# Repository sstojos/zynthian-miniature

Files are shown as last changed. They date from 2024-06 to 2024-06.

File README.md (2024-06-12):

# zynthian-miniature
# Overview
This is repository that store schematics and PCB design for basic PCB with MIDIs, Sound Card and 4 encoders for [zynthian](https://www.zynthian.org). It can also be used for any other raspberry pi audio software. 

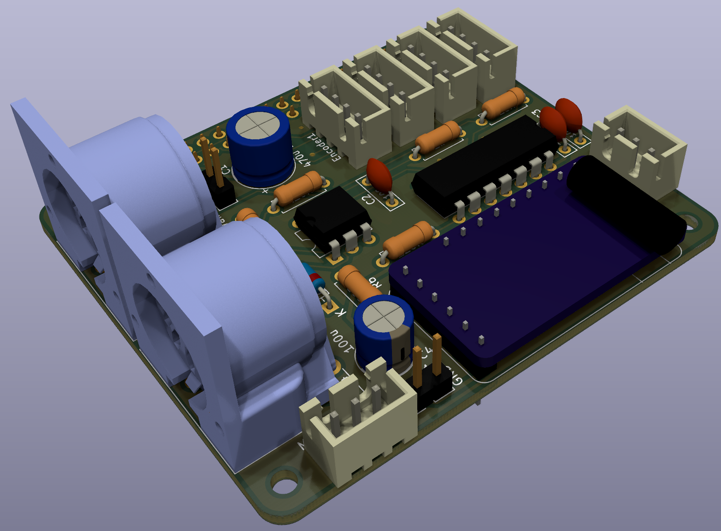
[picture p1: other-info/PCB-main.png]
PCB Main

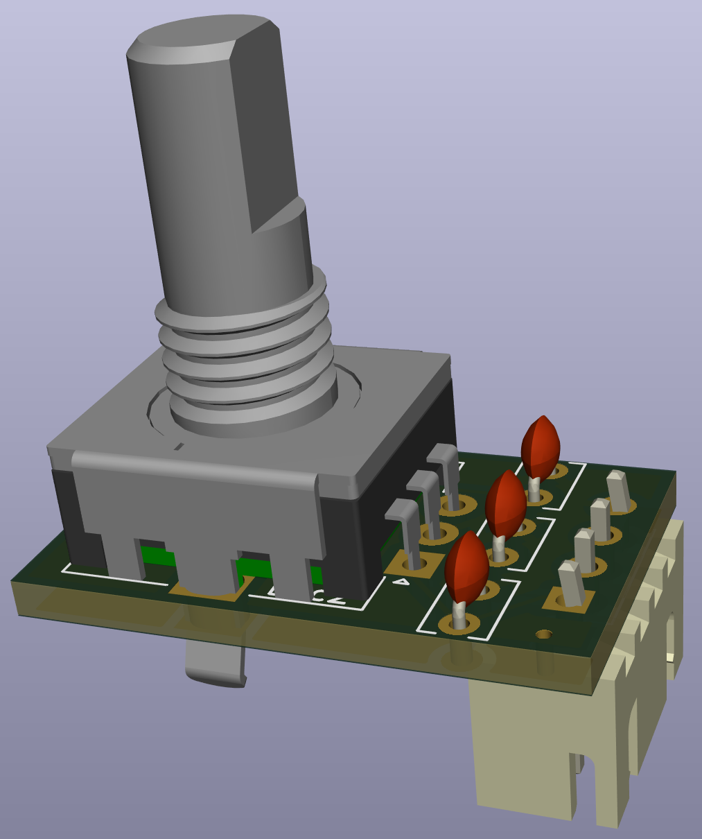
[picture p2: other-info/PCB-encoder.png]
Encoder


This is designed in KiCad 6.0. It is inspired by clumsy MIDI project.

It comes as a single PCB that need to be split into 5: one main PCB and 4 encoder PCBs.
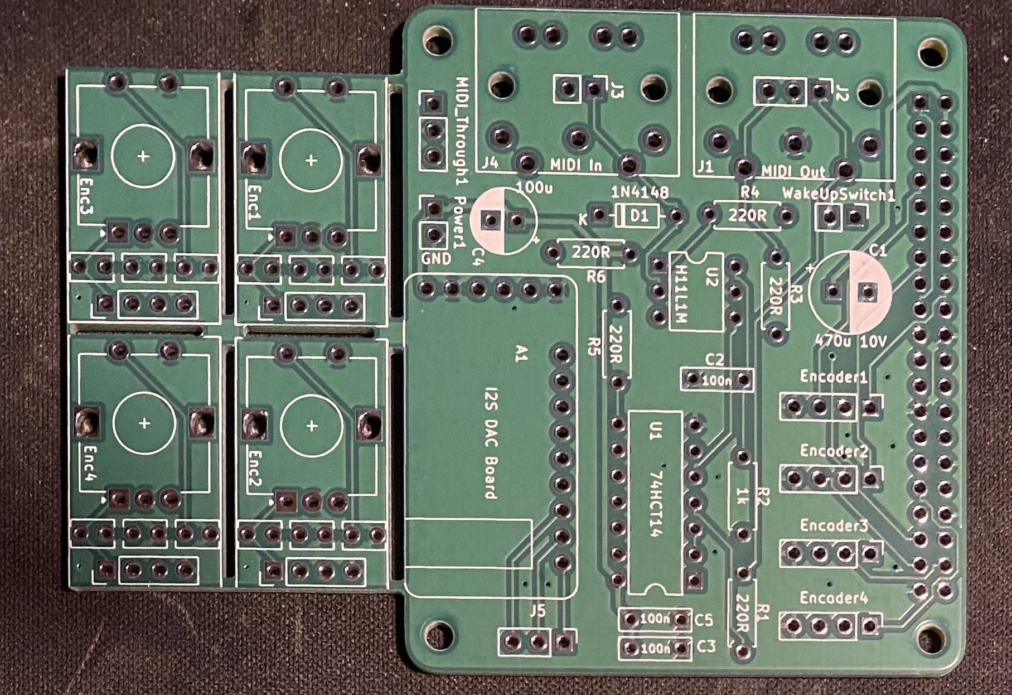
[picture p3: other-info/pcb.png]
5 PCBs


Here is the KiCad schematics screenshot:
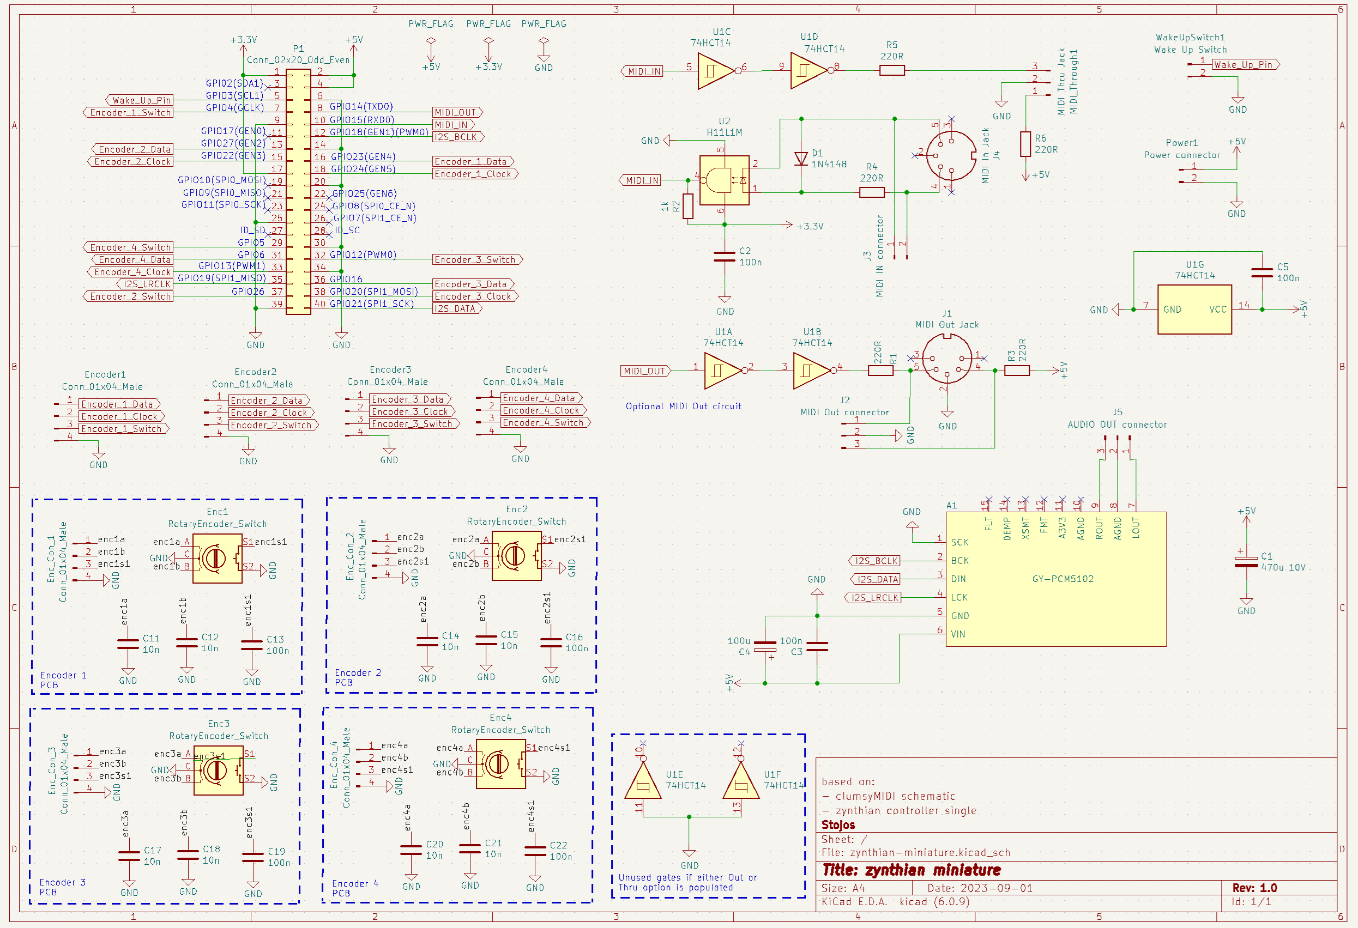
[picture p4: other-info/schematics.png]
schematics


# BOM
Interactive BOM can be found [here](https://raw.githack.com/sstojos/zynthian-miniature/main/bom/ibom.html).

# Usage scenarious

## JST connectors can be replaced with pinheader connectors
Connectors for encoder wiring are JST 2.5mm connectors but standard 2.54mm pin header connectors can also be used instead.

## PCB mounted MIDI connectors can be replaced with panel mounted MIDI connectors
It can be also used  with MIDI and AUDIO panel connectors. Here is how would you wire external panel connectors.
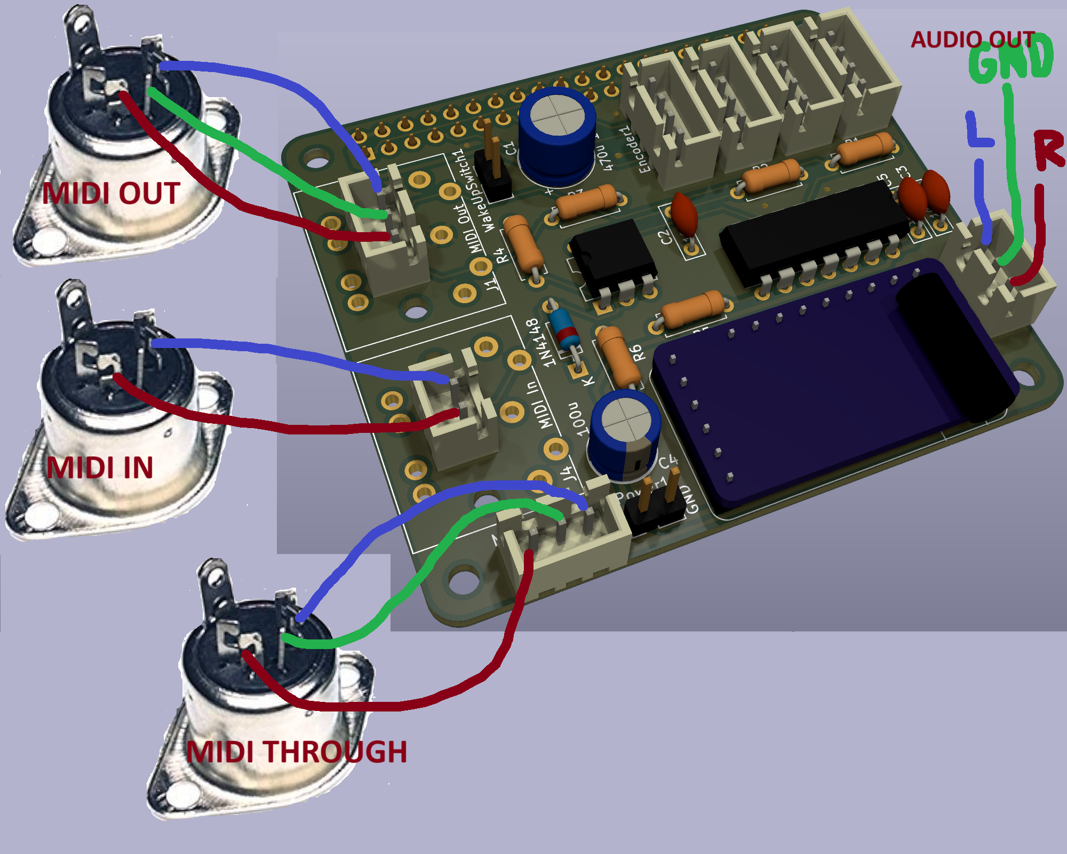
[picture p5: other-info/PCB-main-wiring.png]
external wirring


NOTE: Due to limited size of raspberry pi HUT, JST connectors for MIDI panel connectors are in the same place on PCB where two (IN and OUT) MIDI PCB mountable connectors are. Therefore you can only install JST connectors or MIDI PCB connectors but not both on the same PCB. MIDI through connector is only available through JST connector.

## It can be used with another sound card 
Sound card must not be installed if another sound card is connected to raspberry pi. I2S sound cards can not share the same rpi pins.
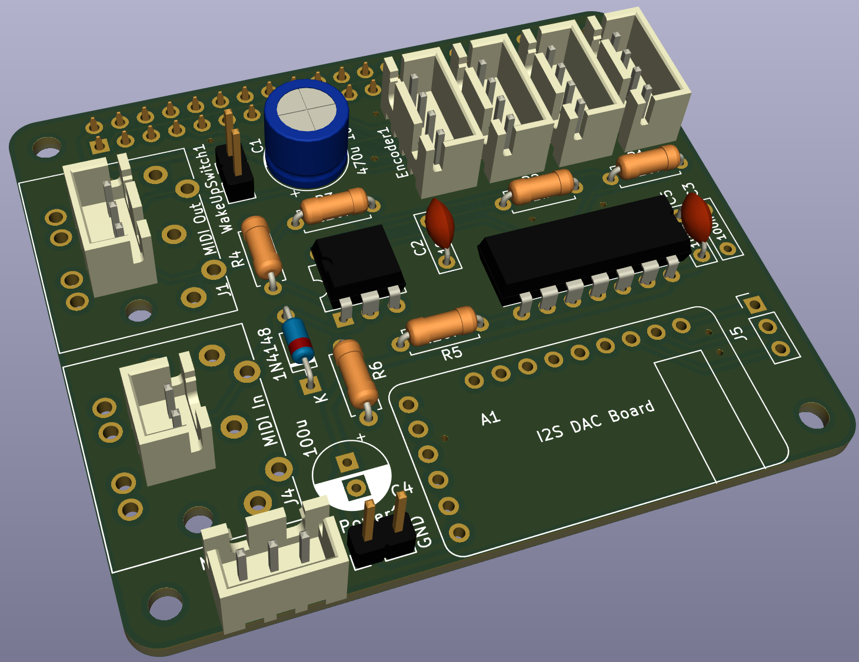
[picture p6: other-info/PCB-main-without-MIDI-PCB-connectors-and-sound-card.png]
without sound card


NOTE: can not be used with another audio card that have AUDIO IN (ADC) such as Hifyberry DAC+ ADC or DAC2 PRO ADC because encoder 3 B pin is wired to RPI pin 38 which is often  used by audio cards with ADC for audio in data. In this case there is a need to brake line from encoder 3 B connector to rpi 38 pin on PCB and  patch (solder wire) from encoder 3 b pin to another available rpi pin. Finnaly, wiring configuration in zynthian webconfig need to be changed accordingly. It is an easy patch. 

# Zynthian Webconfig

## Sound Card
Audio: HifiBerry DAC+ light

## Wiring
* Wiring Layout: Dummies
* Advance Configuration: Enabled
* Encoders A-pins: 5,3,28,23
* Encoders B-pins: 4,2,27,22
* Switches pins: 7,25,26,21

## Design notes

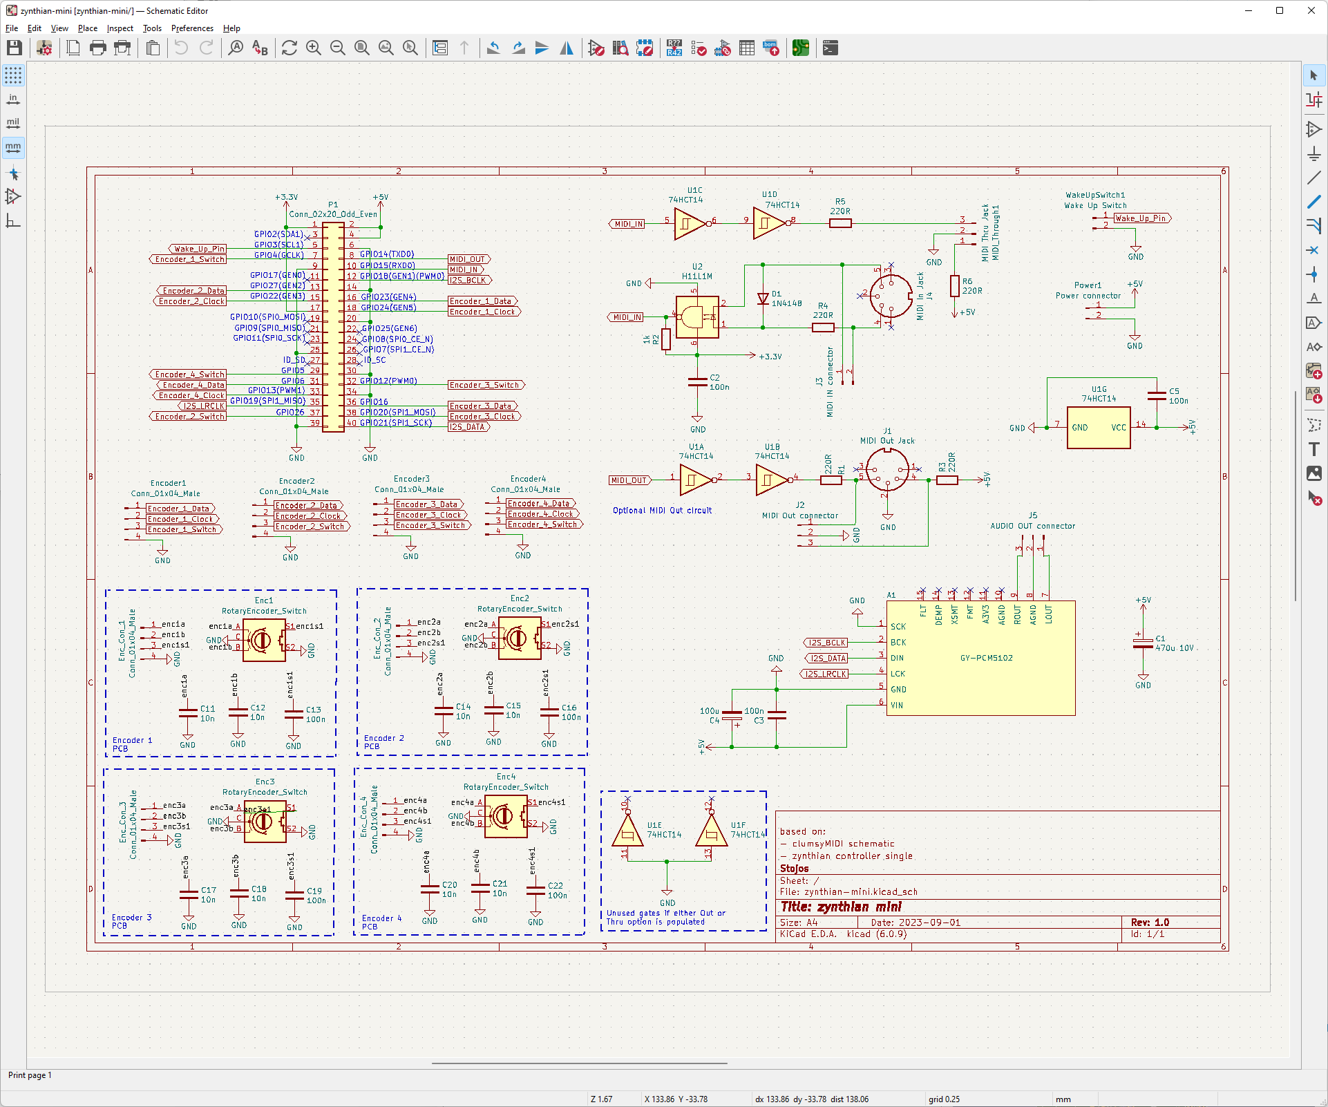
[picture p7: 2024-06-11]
other-info/openscad/zynthian-mini-schematics.png

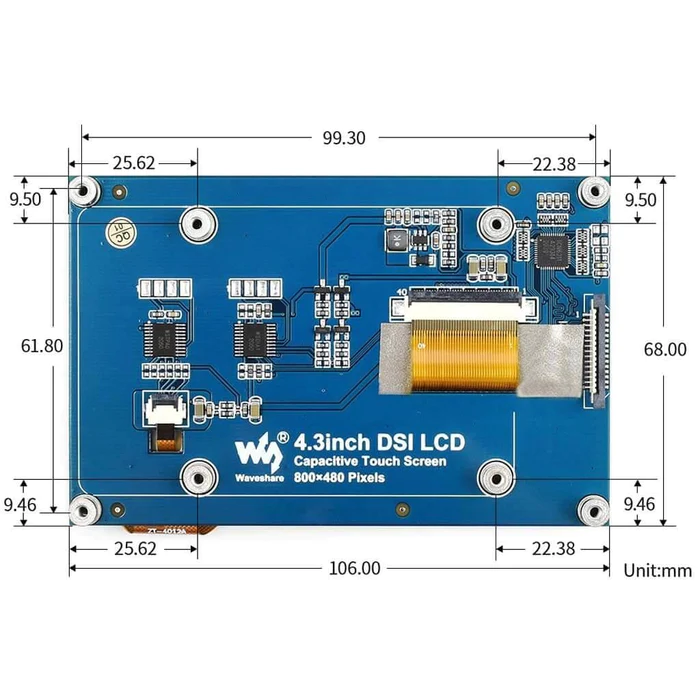
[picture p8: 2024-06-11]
other-info/openscad/waveshare-4.3-dimensions.png

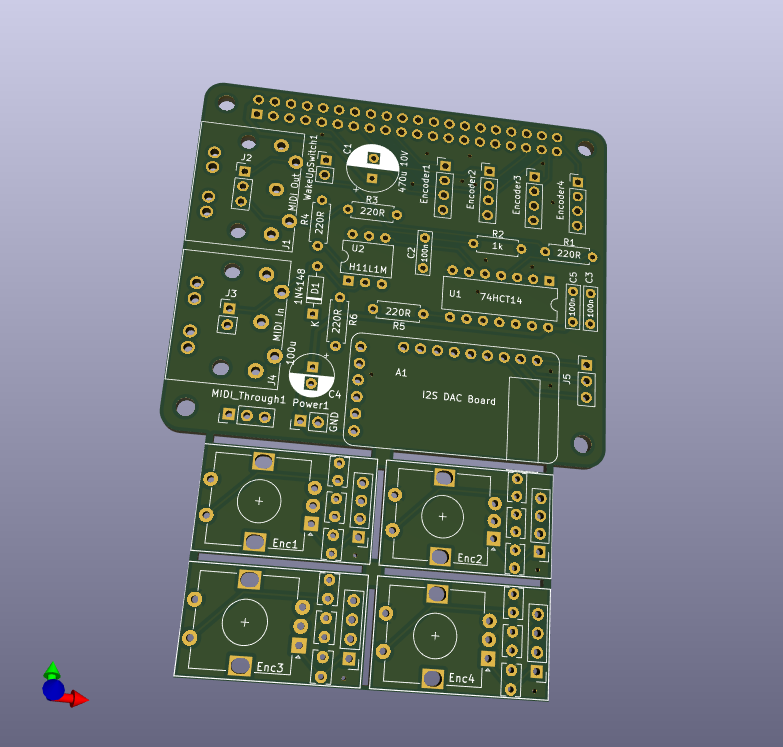
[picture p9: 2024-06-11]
other-info/openscad/zynthian-min-pcbi.png

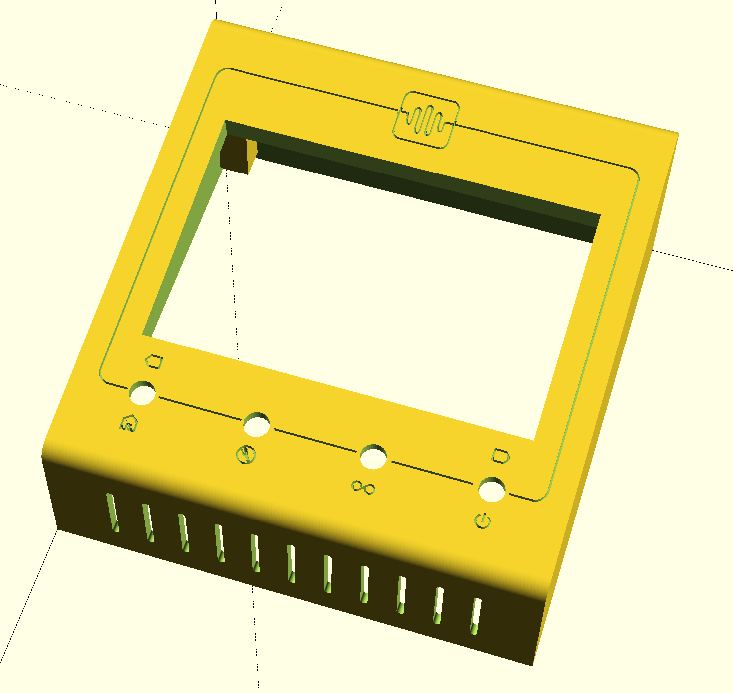
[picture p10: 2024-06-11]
other-info/openscad/zynthina-mini-case-top.png

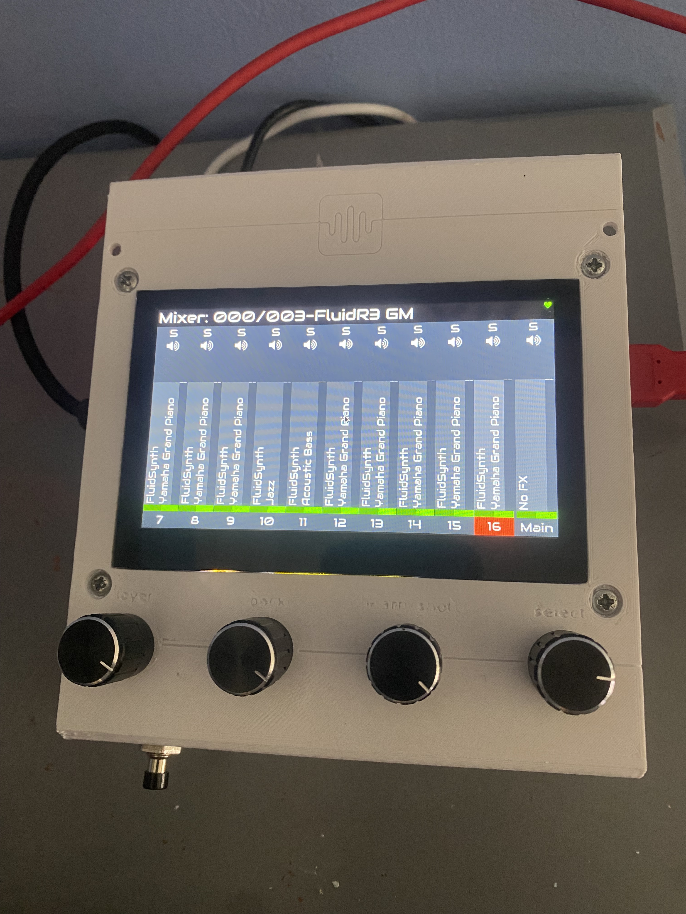
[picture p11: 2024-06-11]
other-info/openscad/zynthian-top.jpg

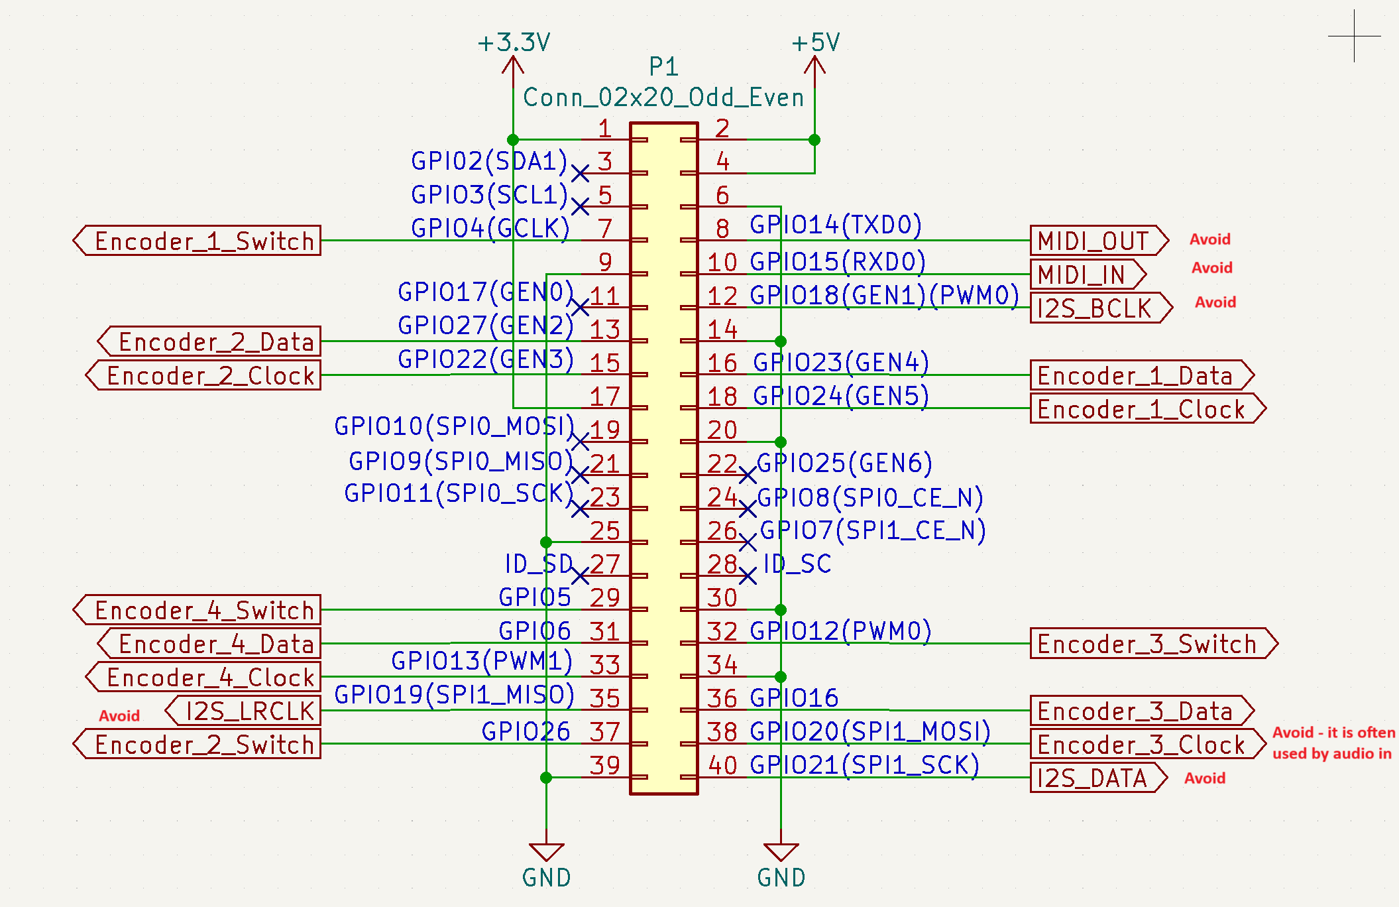
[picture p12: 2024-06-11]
other-info/connector.png

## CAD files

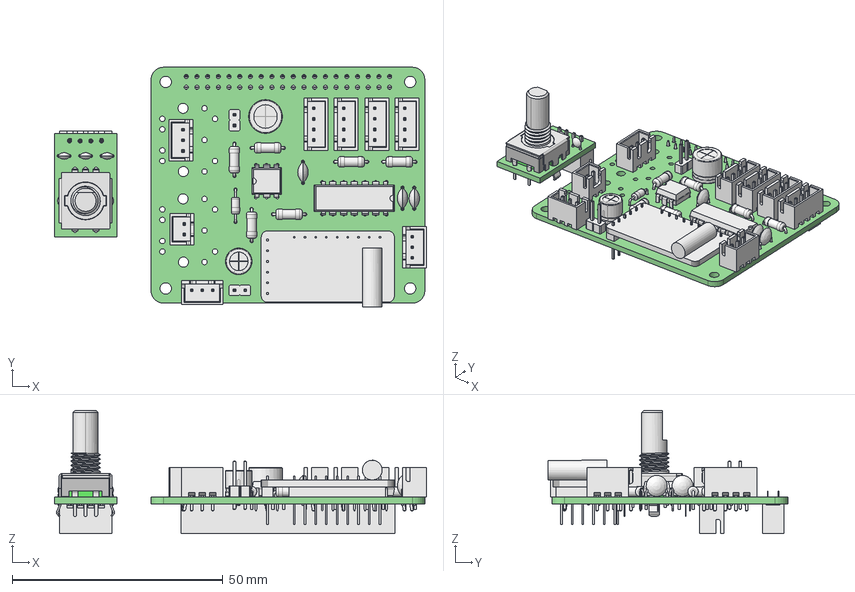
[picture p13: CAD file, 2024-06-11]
other-info/main-board-and-encoder.FCStd
88.3 x 56.9 x 29.2 mm
zynthian-miniature - main-only PCB
_autosave-zynthian-miniature - encoder PCB

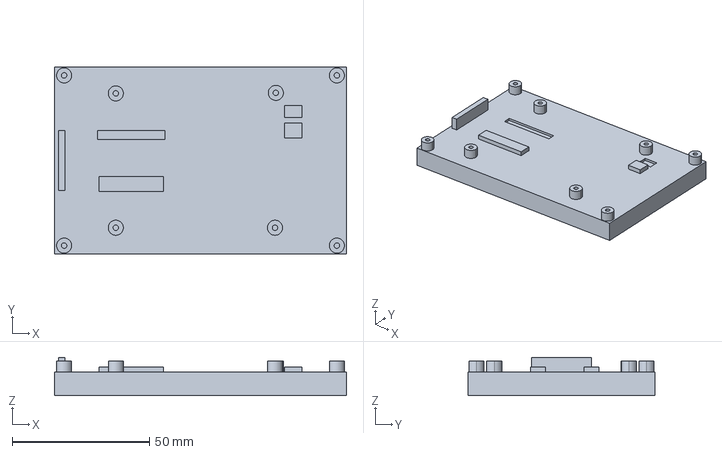
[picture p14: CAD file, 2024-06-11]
other-info/openscad/0329.stp
106.2 x 68.0 x 14.0 mm

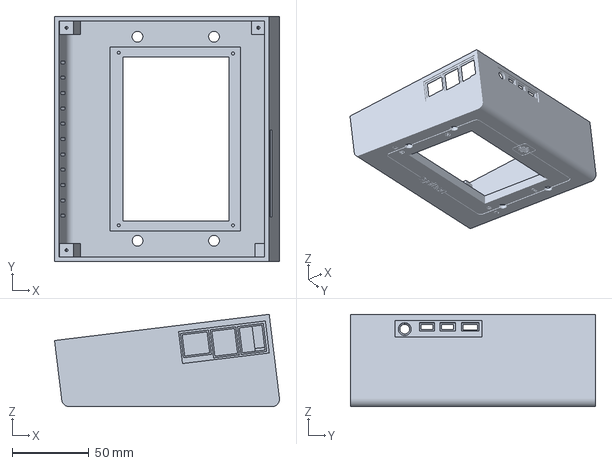
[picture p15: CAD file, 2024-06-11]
other-info/openscad/orcaslicer/top.3mf
146.7 x 160.0 x 60.2 mm

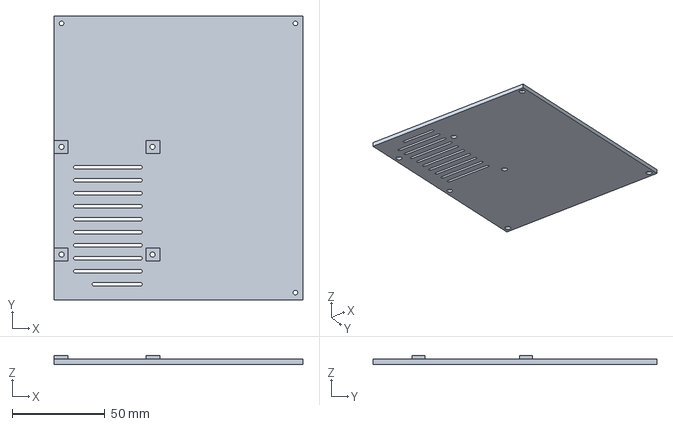
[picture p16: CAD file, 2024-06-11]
other-info/openscad/STLs/bottom.3mf
134.0 x 153.0 x 5.00 mm

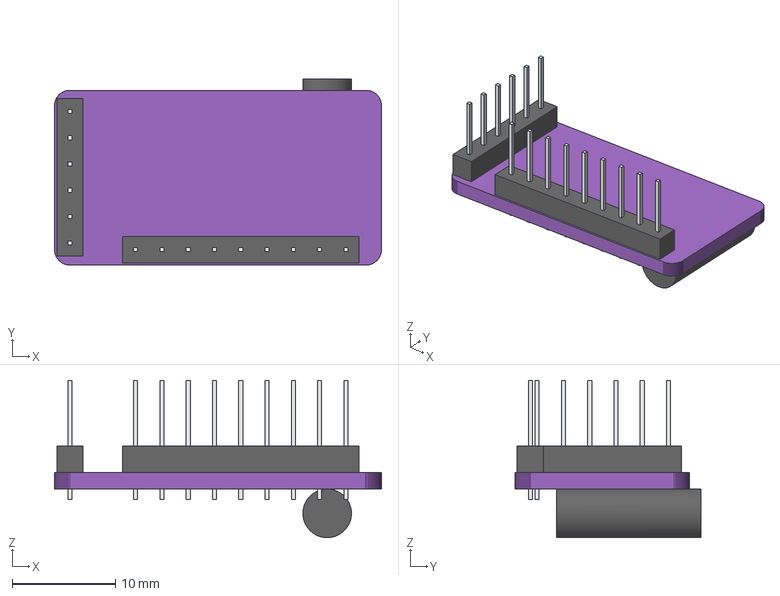
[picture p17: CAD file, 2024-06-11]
PCM5102-I2S.step
31.6 x 18.0 x 15.2 mm

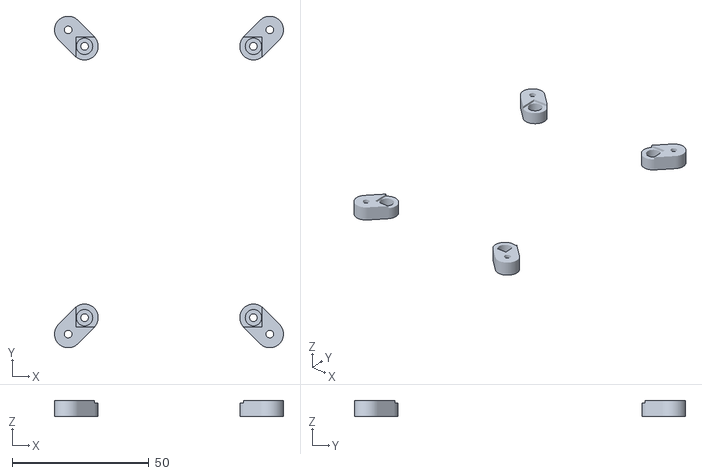
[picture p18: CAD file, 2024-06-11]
other-info/openscad/STLs/screen_mountings.stl
83.8 x 121.3 x 6.00

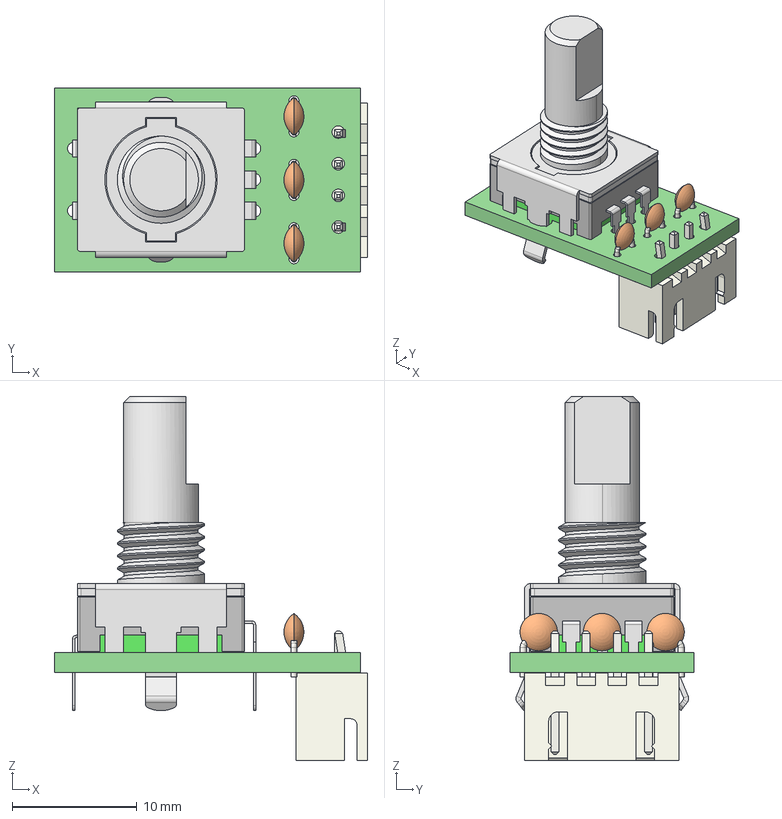
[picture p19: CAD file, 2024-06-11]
zynthian-miniature - encoder.step
25.1 x 14.8 x 29.2 mm
_autosave-zynthian-miniature - encoder PCB

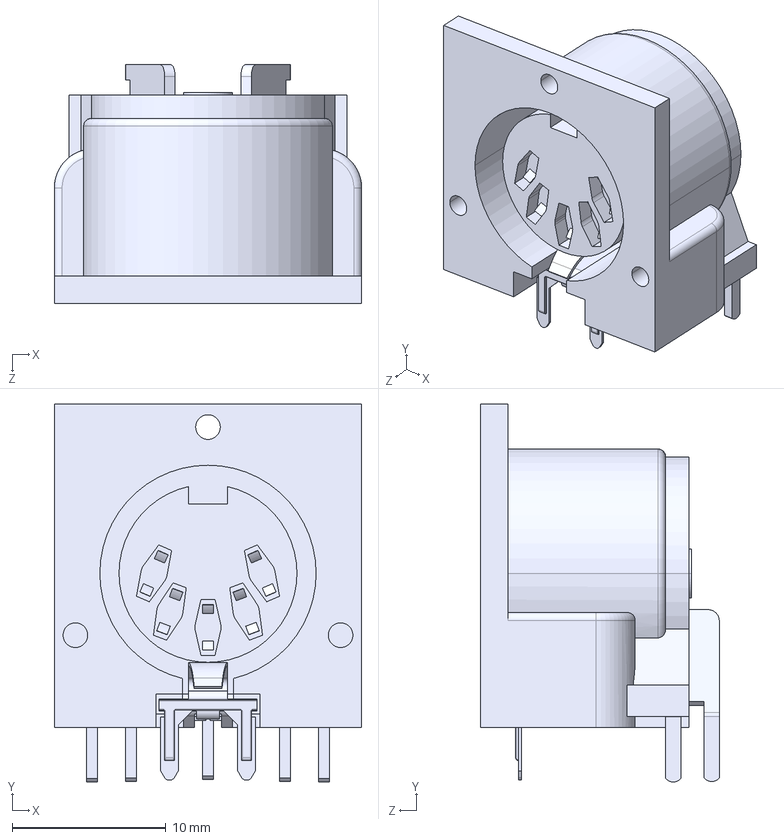
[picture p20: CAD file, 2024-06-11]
midi-connector.step
20.0 x 24.5 x 15.5 mm

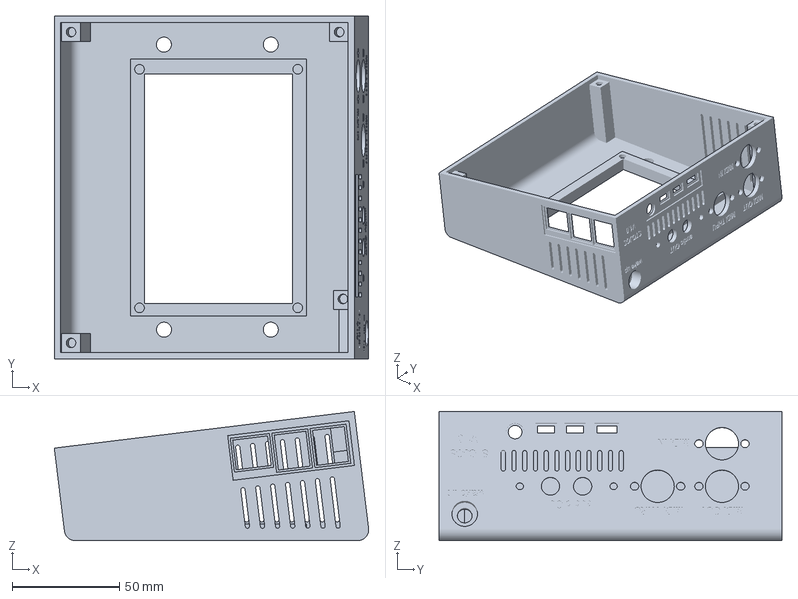
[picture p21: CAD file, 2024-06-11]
other-info/openscad/STLs/top.3mf
146.7 x 160.0 x 60.2 mm

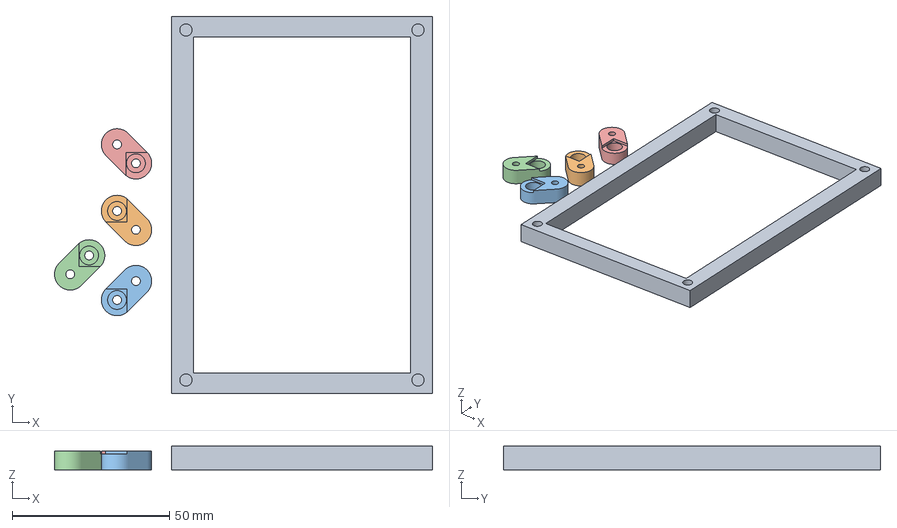
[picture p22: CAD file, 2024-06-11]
other-info/openscad/STLs/mount_test.3mf
120.2 x 120.0 x 7.60 mm
mount_test.stl
screen_mountings.stl_4
screen_mountings.stl_3
screen_mountings.stl_1
screen_mountings.stl_2

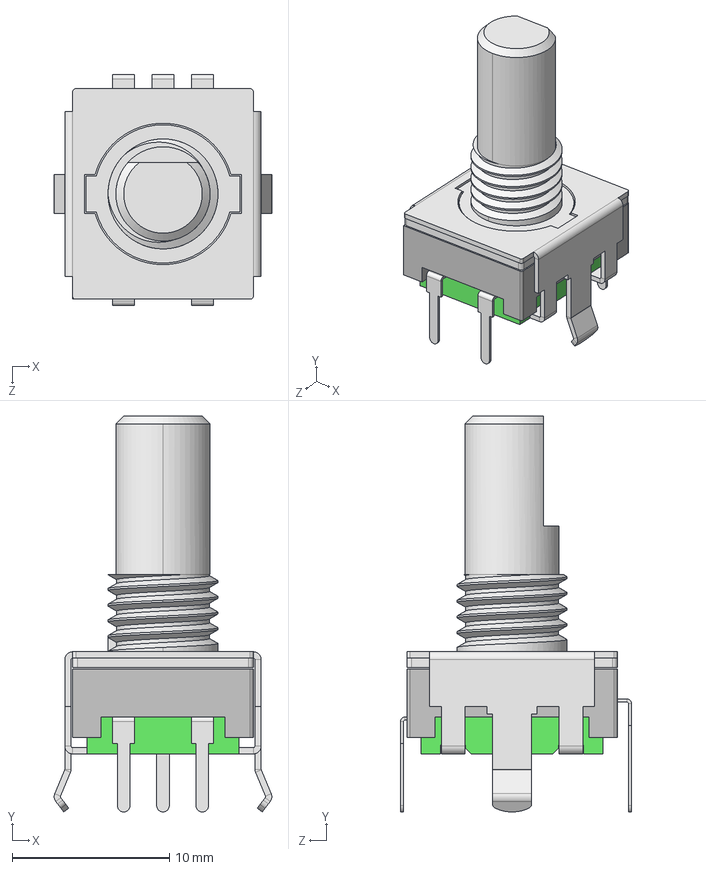
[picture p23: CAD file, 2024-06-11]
rotary-encoder.step
13.9 x 25.2 x 14.7 mm

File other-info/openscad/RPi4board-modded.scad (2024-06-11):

//------------------------------------------------------------------------
// OpenSCAD models of miscellaneous components and devices:
// various Raspberry Pi models, SainSmart Relays, PCD8544 LCD, etc.
//
// Author:      Niccolo Rigacci <niccolo@rigacci.org>
// Version:     1.0 2017-12-14
// License:     GNU General Public License v3.0
// Modified:    by Richard Jelbert 5th January 2021 for RPi 4
//------------------------------------------------------------------------

// Interference for 3D union(), difference() and intersection();
// used to avoid the manifold problem.
interf = 0.2;

//------------------------------------------------------------------------
// Matrix of 2.54 mm pins.
//------------------------------------------------------------------------
module pin_headers(cols, rows) {
    w = 2.54; h = 2.54; p = 0.65;
    for(x = [0 : (cols -1)]) {
        for(y = [0 : (rows  - 1)]) {
            translate([w * x, w * y, 0]) {
                union() {
                    color("black") cube([w, w, h]);
                    //color("gold")  translate([(w - p) / 2, (w - p) / 2, -3]) cube([p, p, 11.54]);
                }
            }
        }
    }
}

//------------------------------------------------------------------------
// Sub-models for the Raspberry Pi 4 Model
//------------------------------------------------------------------------

module ethernet_connector(x, y, z, cut=false) {
    if(!cut) {
        color("silver") cube([x, y, z]);
    }
    if(cut) {
        translate([-0.5,5,-0.5]) color("silver") cube([x+1, y, z+1]);
    }
}
module usb_connector(x, y, z, cut=false) {
    f = 0.6; // Flange
    if(!cut) {
        color("silver") cube([x, y, z]);
        translate([-f, y - f, -f])
            color("silver") cube([x + f * 2, f, z + f * 2]);
    }
    if(cut) {
        //color("silver") cube([x, y, z]);
        translate([-f-0.5, 5, -f-0.5])
            color("silver") cube([x + f * 2+1, y+10, z + f * 2+1]);
    }
}
module hdmi_connector(x, y, z, cut=false) {
    if(!cut) {
        color("silver") cube([x, y, z]);
    }
    if(cut) {
        translate([3,-0.5,-0.5]) color("silver") cube([x+5, y+1, z+1]);
    }
}
module usbc_connector(x, y, z, cut=false) {
    color("silver") cube([x, y, z]);
}
module capacitor(d, h) {
    color("silver") cylinder(r=(d / 2), h=h);
}
module micro_sd_card() {
    color("silver")   translate([1.5,  0.0, -1.5]) cube([12, 12.5, 1.5]);
    color("orange") translate([2, -3.2, -1.0]) cube([11, 15, 1.0]);
}
module audio_video(size_x, cut=false) {
    fn = 64;
    if(!cut) {
        color([58/255, 58/255, 58/255]) {
            cube([size_x, 7, 5.6]);
            translate([size_x, 7 / 2, 5.6 / 2]) rotate([0,90,0]) cylinder(d=5.6, h=2.6, $fn = fn);
        }
    }
    if(cut) {
        color([58/255, 58/255, 58/255]) {
            cube([size_x, 7, 5.6]);
            translate([size_x, 7 / 2, 5.6 / 2]) rotate([0,90,0]) cylinder(d=5.6+0.5, h=10, $fn = fn);
        }
    }
}
module cpu() {
    color("silver")
    cube([15,15,2.4]);
}

module ram() {
    color("black")
    cube([15,10.2,1]);
}

module wifi(){
    color("silver")
    cube([12,10,1.5]); 
}   

module cameracon(){
    color("black")
    cube([22,2.5,5.5]);
}


//------------------------------------------------------------------------
// Raspberry Pi 4 Model B
//------------------------------------------------------------------------
//board_raspberrypi_4_model_b(cut=true);
//board_raspberrypi_4_model_b(cut=false);
module board_raspberrypi_4_model_b(cut=false) {
    fn = 64;
    x  = 56;     y = 85;    z = 1.40;  // Measured PCB size
    ex = 15.9; ey = 21.5; ez = 13.5;   // Ethernet port size
    ux = 13.1; uy = 17.1; uz = 15.5;   // Measured USB connector size
    hx = 7.80; hy = 6.5; hz = 3;  // Measured micro HDMI connector size
    mx =  7.60; my =  9; mz = 3.20;  // Measured USB-C power connector size
    // The origin is the lower face of PCB.
    if(!cut) {
        translate([0, 0, z]) {
            
            translate([56-32.5-7.5,3.5+25.75-7.5,0])  cpu();
            translate([56-32.5-7.5,3.5+43.75-7.5,0])  ram();
            translate([7,6.5,0])    wifi();
            translate([(56/2)-12,(4-1.25),0]) cameracon();
            translate([(56)-22.3,(45),0]) cameracon();
            translate([1.0, 7.1, 0])    pin_headers(2, 20);
            translate([x-(ex/2)-45.75, y - ey + 2.1, 0])    ethernet_connector(ex, ey, ez);
            translate([x-(ux/2)-27, 85 - uy + 2.1, 0])  usb_connector(ux, uy, uz);
            translate([x-(ux/2)-9, 85 - uy + 2.1, 0])   usb_connector(ux, uy, uz);
            translate([x - hx + 1.8, (3.5+7.7+14.8-(hy/2)), 0]) hdmi_connector(hx, hy, hz);
            translate([x - hx + 1.8, (3.5+7.7+14.8+13.5-(hy/2)), 0])    hdmi_connector(hx, hy, hz);
            translate([x - 12.8, 50, 0])    audio_video(12.8);
            translate([x - mx + 1, (3.5+7.7-(my/2)), 0])    usbc_connector(mx, my, mz);
            //translate([20.5, 0.8, -z])  micro_sd_card();
            translate([0, 0, -z]) {
                color("green") linear_extrude(height=z)
                    difference() {
                        hull() {
                            translate([  3,   3]) circle(r=3, $fn = fn);
                            translate([x-3,   3]) circle(r=3, $fn = fn);
                            translate([x-3, y-3]) circle(r=3, $fn = fn);
                            translate([  3, y-3]) circle(r=3, $fn = fn);
                        }
                        raspberrypi_4_model_b_holes();
                    }
            }
        }
    }
    
    if(cut) {
       translate([0, 0, z]) {
            translate([x-(ex/2)-45.75, y - ey + 2.1, 0])    ethernet_connector(ex, ey, ez, cut=true);
            translate([x-(ux/2)-27, 85 - uy + 2.1, 0])  usb_connector(ux, uy, uz, cut=true);
            translate([x-(ux/2)-9, 85 - uy + 2.1, 0])   usb_connector(ux, uy, uz, cut=true);
            translate([x - hx + 1.8, (3.5+7.7+14.8-(hy/2)), 0]) hdmi_connector(hx, hy, hz, cut=true);
            translate([x - hx + 1.8, (3.5+7.7+14.8+13.5-(hy/2)), 0])    hdmi_connector(hx, hy, hz, cut=true);
            translate([x - 12.8, 50, 0])    audio_video(12.8, cut=true);
            //translate([x - mx + 1, (3.5+7.7-(my/2)), 0])    usbc_connector(mx, my, mz, cut=true);
       }
   }
}

//------------------------------------------------------------------------
// Holes for Raspberry Pi 4 Model B
//------------------------------------------------------------------------
module raspberrypi_4_model_b_holes() {
    x = 56;
    fn = 64;
    translate([3.5, 3.5])            circle(r=(2.75 / 2), $fn=fn);
    translate([(x - 3.5), 3.5])      circle(r=(2.75 / 2), $fn=fn);
    translate([3.5, 3.5 + 58])       circle(r=(2.75 / 2), $fn=fn);
    translate([(x - 3.5), 3.5 + 58]) circle(r=(2.75 / 2), $fn=fn);
}



//board_raspberrypi_4_model_b();

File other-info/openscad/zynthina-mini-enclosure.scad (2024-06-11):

$fn=124;


//render_all_disassembled();
color("SaddleBrown") render_all_assembled();

module render_all_assembled() {    
    

}

module render_all_disassembled() {    
    
}

//mounting();
module mounting() {

    difference() {
        union() {
            hull() {
                cylinder(r=5,h=10);
            translate([-7,-7,0])cylinder(r=5,h=10);
            }
            hull() {
                translate([-1.5,-1.5,0])cylinder(r=5,h=3);
                translate([-7,-7,0])cylinder(r=5,h=3);
            }
        }
        translate([0,0,3])cylinder(r=3,h=4.5);
        translate([0,0,5])cylinder(r=1.4,h=8);
        translate([-3.25,-3.25,-1]) cube([10,10,5.5]);
        translate([-7,-7,-1])cylinder(r=1,h=5);
        translate([-7,-7,10-4])cylinder(r=1,h=5);
    }
}


top_panel(part=0);
module top_panel(part=0) {
// zyntian-top.svg is 150 width and 110 height
    difference() {
        union() {
            top_with_holes(part=part);
        }
        translate([110+2.2, 0, 41]) rotate([0,8.7,0]) rotate([0,0,90]) zynthian_top(cut=false); 
        translate([110+2.2, 0, 41]) rotate([0,7.1,0]) rotate([0,0,90]) zynthian_top(cut=true); 
    }
    
    //screen mounting bottom left
    translate([28.5, 25.5, 46]) rotate([0,9,0]) screen_mounting();

}


//zynthian_top();
// part: 1 left
// part: 2 center
// part: 3 right
// part: 4 all
// cut: true - render wholes only
module zynthian_top(cut=false) {
    if (!cut) {
        linear_extrude(3) import("zynthian-top.svg");
    }
    if (cut) {
        translate([0,0,-5]) linear_extrude(10) import("zynthian-holes.svg");
    }
}





//top_with_holes(part=3);
// top with hole is the template for rendering the top lid for number of sections
module top_with_holes(part=0) {
    difference() {
        lenght=150;
        top(lenght=lenght, part=part);
//        // holes for top screews
//        translate([0,-6,0])
//        translate([8.65,0,23.8-13])
//        translate([13,9,34]) cylinder(h=15,r1=1.75,r2=1.75,center=false);
//        translate([0,lenght-6,0])
//        translate([8.65,0,23.8-13])
//        translate([13,3,34]) cylinder(h=15,r1=1.75,r2=1.75,center=false);
//        //holes for front screew
//        translate([133,5,15]) rotate ([0,90,0]) cylinder(h=10,r1=1.75,r2=1.75,center=false);
//        translate([133,lenght-5,15]) rotate ([0,90,0]) cylinder(h=10,r1=1.75,r2=1.75,center=false);
        
        
    }

}

//top(lenght=20, part=0);
// top is the template for rendering the top lid of any lenght
// part: 0 - render all
// part: 1 - render only rear
// part: 2 - render only top
// part: 3 - render only front
module top(lenght=10, part=0) {
    // top takes 4 internal parts of 1" 1/4 which is in total 5" - which is 127mm
    difference() {
        case(lenght=lenght, tolerance=2.2);
        translate([2.2,2.2,-0.1]) case(lenght=lenght-2*2.2, tolerance=0);
    }
}

            
//case(lenght=10, tolerance=0);
module case(lenght=200, tolerance=0) {
    translate([0,lenght,0]) rotate ([90,0,0])
    hull() {
        linear_extrude(height = lenght) polygon( points=[[0,0],[0,52+tolerance],[0+5,52+5+tolerance],[110+tolerance*2-5,36+tolerance+5], [110+tolerance*2,36+tolerance],[110+tolerance*2,0]]);
        translate([0+5,52+tolerance,0])
            cylinder(h = lenght, r1 = 5, r2 = 5, center = false);
        translate([110+tolerance*2-5,36+tolerance,0]) cylinder(h = lenght, r1 = 5, r2 = 5, center = false);
    }
}

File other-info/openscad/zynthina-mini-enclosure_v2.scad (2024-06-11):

$fn=124;
include <RPi4board-modded.scad>;

//render_all_assembled();
module render_all_assembled() {    
   top();
//   translate([4,4.5,5]) raspberry_and_card();
//   bottom();  
}

module render_all_disassembled() {    
    
}


//bottom();
module bottom() {
    difference() {
        union() {
            translate([3.5,3.5,0]) cube([135-1,160-6-1,3]);
            
            //rp4 base
            translate([3.5,24.5,0]) cube([7.5,7,5]);
            translate([3.5,82.5,0]) cube([7.5,7,5]);
            translate([53,24.5,0]) cube([7.5,7,5]);
            translate([53,82.5,0]) cube([7.5,7,5]);
        }
        
        //rp4 holes
        translate([32,51,14])
        rotate([0,0,-90])
        {
            //boreholes for Raspberry Pi
            translate([4, 0, -9.6])
                rotate([0, 0, 0]) {
                translate([-10, 0, 0]) {
                    translate([-58/2,-49/2,-1]) {
                        cylinder(h=7, d=2.75, center=true);
                        translate([0,0,-2.7]) cylinder(h=1.6, r1=2.2, r2=1.4, center=true);
                    }
                    translate([-58/2, 49/2,-1]) {
                        cylinder(h=7, d=2.75, center=true);
                        translate([0,0,-2.7]) cylinder(h=1.6, r1=2.2, r2=1.4, center=true);
                    }
                    translate([ 58/2,-49/2,-1]) {
                        cylinder(h=7, d=2.75, center=true);
                        translate([0,0,-2.7]) cylinder(h=1.6, r1=2.2, r2=1.4, center=true);
                    }
                    translate([ 58/2, 49/2,-1]) {
                        cylinder(h=7, d=2.75, center=true);
                        translate([0,0,-2.7]) cylinder(h=1.6, r1=2.2, r2=1.4, center=true);
                    }
                }
            }
        }
        
        // ventilation gril
        for ( i = [1:1:10]) {
            //render first grill shorter so that there is a space to glue rubber legs
            if (i==1) {
                translate([15+10,5+i*7,-1]) rotate([0,0,-90])
                hull() {
                    cylinder ( h=10,r1=1,r2=1,center=true );
                    translate([0,25,0]) cylinder ( h=10,r1=1,r2=1,center=true );
                }
            } else {
                translate([15,5+i*7,-1]) rotate([0,0,-90])
                hull() {
                    cylinder ( h=10,r1=1,r2=1,center=true );
                    translate([0,35,0]) cylinder ( h=10,r1=1,r2=1,center=true );
                }
            }
        }

        // main holes for scews thatwill connect it to top 
        //translate([7.5,7.5,-1]) cylinder(h=12, r1=1.75, r2=1.75, center=false);
        translate([7.5,160-7.5,-1]) cylinder(h=12, d=2.5, center=false);
        translate([135-1.5,7.5,-1]) cylinder(h=12, d=2.5, center=false);
        translate([135-1.5,160-7.5,-1]) cylinder(h=12, d=2.5, center=false);
        
        //hole enlargement for screw head
        translate([7.5,160-7.5,-0.1]) cylinder(h=1.6, r1=2.2, r2=1.4, center=false);        
        translate([135-1.5,7.5,-0.1]) cylinder(h=1.6, r1=2.2, r2=1.4, center=false);
        translate([135-1.5,160-7.5,-0.1]) cylinder(h=1.6, r1=2.2, r2=1.4, center=false);

    }
}
//display(cut=true);
module display(cut=false) {
    if(!cut) {
        //display is 106x68x8.6
        translate([68,0,0]) rotate([180,0,180])
        color("blue") translate([68/2,106/2,3.35]) rotate([0,0,90]) import("0329.stl", convexity = 5);
    }
    if (cut) {
        translate([-0.5,-0.5,-14])
        union() {
            //screen is 106x68x8.6 but add 1 mm on each side for posible fit
            cube([69, 107, 16]); 
            translate([0.5,0.5,14]) screen_mounting(post_height=6, cut=true);
        }
    }
}

// raspberry 4.3 screen mounting
// mounting screws for case should be 3.75x3.75 mm ouside the each corner 
//screen_mounting();
//screen_mounting(cut=false);
module screen_mounting(post_height=6, cut=false) {

   if(!cut){
       //  display center mounitng is:
       //  DOWN-UP distance from corner of teh screen: "(68-61.8)/2: ", 3.1
       //  LEFT/RIGHT: "(106-99.3)/2: ", 3.35
       difference() {
           union() {
            //top left
            translate([(68-61.8)/2,(106-99.3)/2,-8.6+1]) rotate([180,0,90]) 
                difference() {
                    hull() {
                        cylinder(r=5,h=post_height);
                        translate([-6,-6,0])cylinder(r=5,h=post_height);
                    }
                    translate([0,0,-0.1])cylinder(r=3,h=5);
                    translate([0,0,1])cylinder(r=1.4,h=8);
                    translate([-3,-6.3,5]) rotate([0,0,45]) linear_extrude(height = 3) text("1", font = "Liberation Sans:style=Bold", size = 5);
                }
                
            //top right
            translate([(68-61.8)/2,99.3+(106-99.3)/2,-8.6+1]) rotate([180,0,0])
                difference() {
                    hull() {
                        cylinder(r=5,h=post_height);
                        translate([-6,-6,0])cylinder(r=5,h=post_height);
                    }
                    translate([0,0,-0.1])cylinder(r=3,h=5);
                    translate([0,0,1])cylinder(r=1.4,h=8); 
                    translate([-3,-6.3,5]) rotate([0,0,45]) linear_extrude(height = 3) text("2", font = "Liberation Sans:style=Bold", size = 5);

                }
                
            //bottom right
            translate([61.8+(68-61.8)/2,99.3+(106-99.3)/2,-8.6+1]) rotate([180,0,-90])
                difference() {
                    hull() {
                        cylinder(r=5,h=post_height);
                        translate([-6,-6,0])cylinder(r=5,h=post_height);
                    }
                    translate([0,0,-0.1])cylinder(r=3,h=5);
                    translate([0,0,1])cylinder(r=1.4,h=8);
                   translate([-3,-6.3,5]) rotate([0,0,45]) linear_extrude(height = 3) text("3", font = "Liberation Sans:style=Bold", size = 5); 
                }
                
            // bottom left
            translate([61.8+(68-61.8)/2,(106-99.3)/2,-8.6+1]) rotate([180,0,180]) 
                difference() {
                    hull() {
                        cylinder(r=5,h=post_height);
                        translate([-6,-6,0])cylinder(r=5,h=post_height);
                    }
                    translate([0,0,-0.1])cylinder(r=3,h=5);
                    translate([0,0,1])cylinder(r=1.4,h=8); 
                    translate([-3,-6.3,5]) rotate([0,0,45]) linear_extrude(height = 3) text("4", font = "Liberation Sans:style=Bold", size = 5);
                }
            }
       
            // cut small edges  (1.mm deep) for screen
            //screen is 106x68x8.6mm but add 0.1 on each side
            translate([-0.1,-0.1,-8.6])cube([68.2, 106.2,8.6]);
            
            // mount holes
            //top left hole for mount
            translate([(68-61.8)/2+1,(106-99.3)/2+1,-8.6+1]) rotate([180,0,90]) 
                translate([-7,-7,-1])cylinder(r=1.4,h=8); 
            //top right hole for mount
            translate([(68-61.8)/2+1,99.3+(106-99.3)/2-1,-8.6+1]) rotate([180,0,0])
                    translate([-7,-7,-1])cylinder(r=1.4,h=8); 
            //bottom right hole for mount
            translate([61.8+(68-61.8)/2-1,99.3+(106-99.3)/2-1,-8.6+1]) rotate([180,0,-90])
                    translate([-7,-7,-1])cylinder(r=1.4,h=8);             
            // bottom left hole for mount
            translate([61.8+(68-61.8)/2-1,(106-99.3)/2+1,-8.6+1]) rotate([180,0,180]) 
                    translate([-7,-7,-1])cylinder(r=1.4,h=8);             
        }
    }
    
    if (cut) {
       translate([0,0,6]) {
            // mount holes
            //top left hole for mount
            translate([(68-61.8)/2+1,(106-99.3)/2+1,-8.6+1]) rotate([180,0,90]) 
                translate([-7,-7,-1])cylinder(d=4.5,h=8); 
            //top right hole for mount
            translate([(68-61.8)/2+1,99.3+(106-99.3)/2-1,-8.6+1]) rotate([180,0,0])
                    translate([-7,-7,-1])cylinder(d=4.5,h=8); 
            //bottom right hole for mount
            translate([61.8+(68-61.8)/2-1,99.3+(106-99.3)/2-1,-8.6+1]) rotate([180,0,-90])
                    translate([-7,-7,-1])cylinder(d=4.5,h=8);             
            // bottom left hole for mount
            translate([61.8+(68-61.8)/2-1,(106-99.3)/2+1,-8.6+1]) rotate([180,0,180]) 
                    translate([-7,-7,-1])cylinder(d=4.5,h=8);             
       }
    }
}
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

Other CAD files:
other-info/openscad/0329.stl
other-info/openscad/STLs/bottom.stl
other-info/openscad/STLs/mount_test.stl
other-info/openscad/STLs/top.stl

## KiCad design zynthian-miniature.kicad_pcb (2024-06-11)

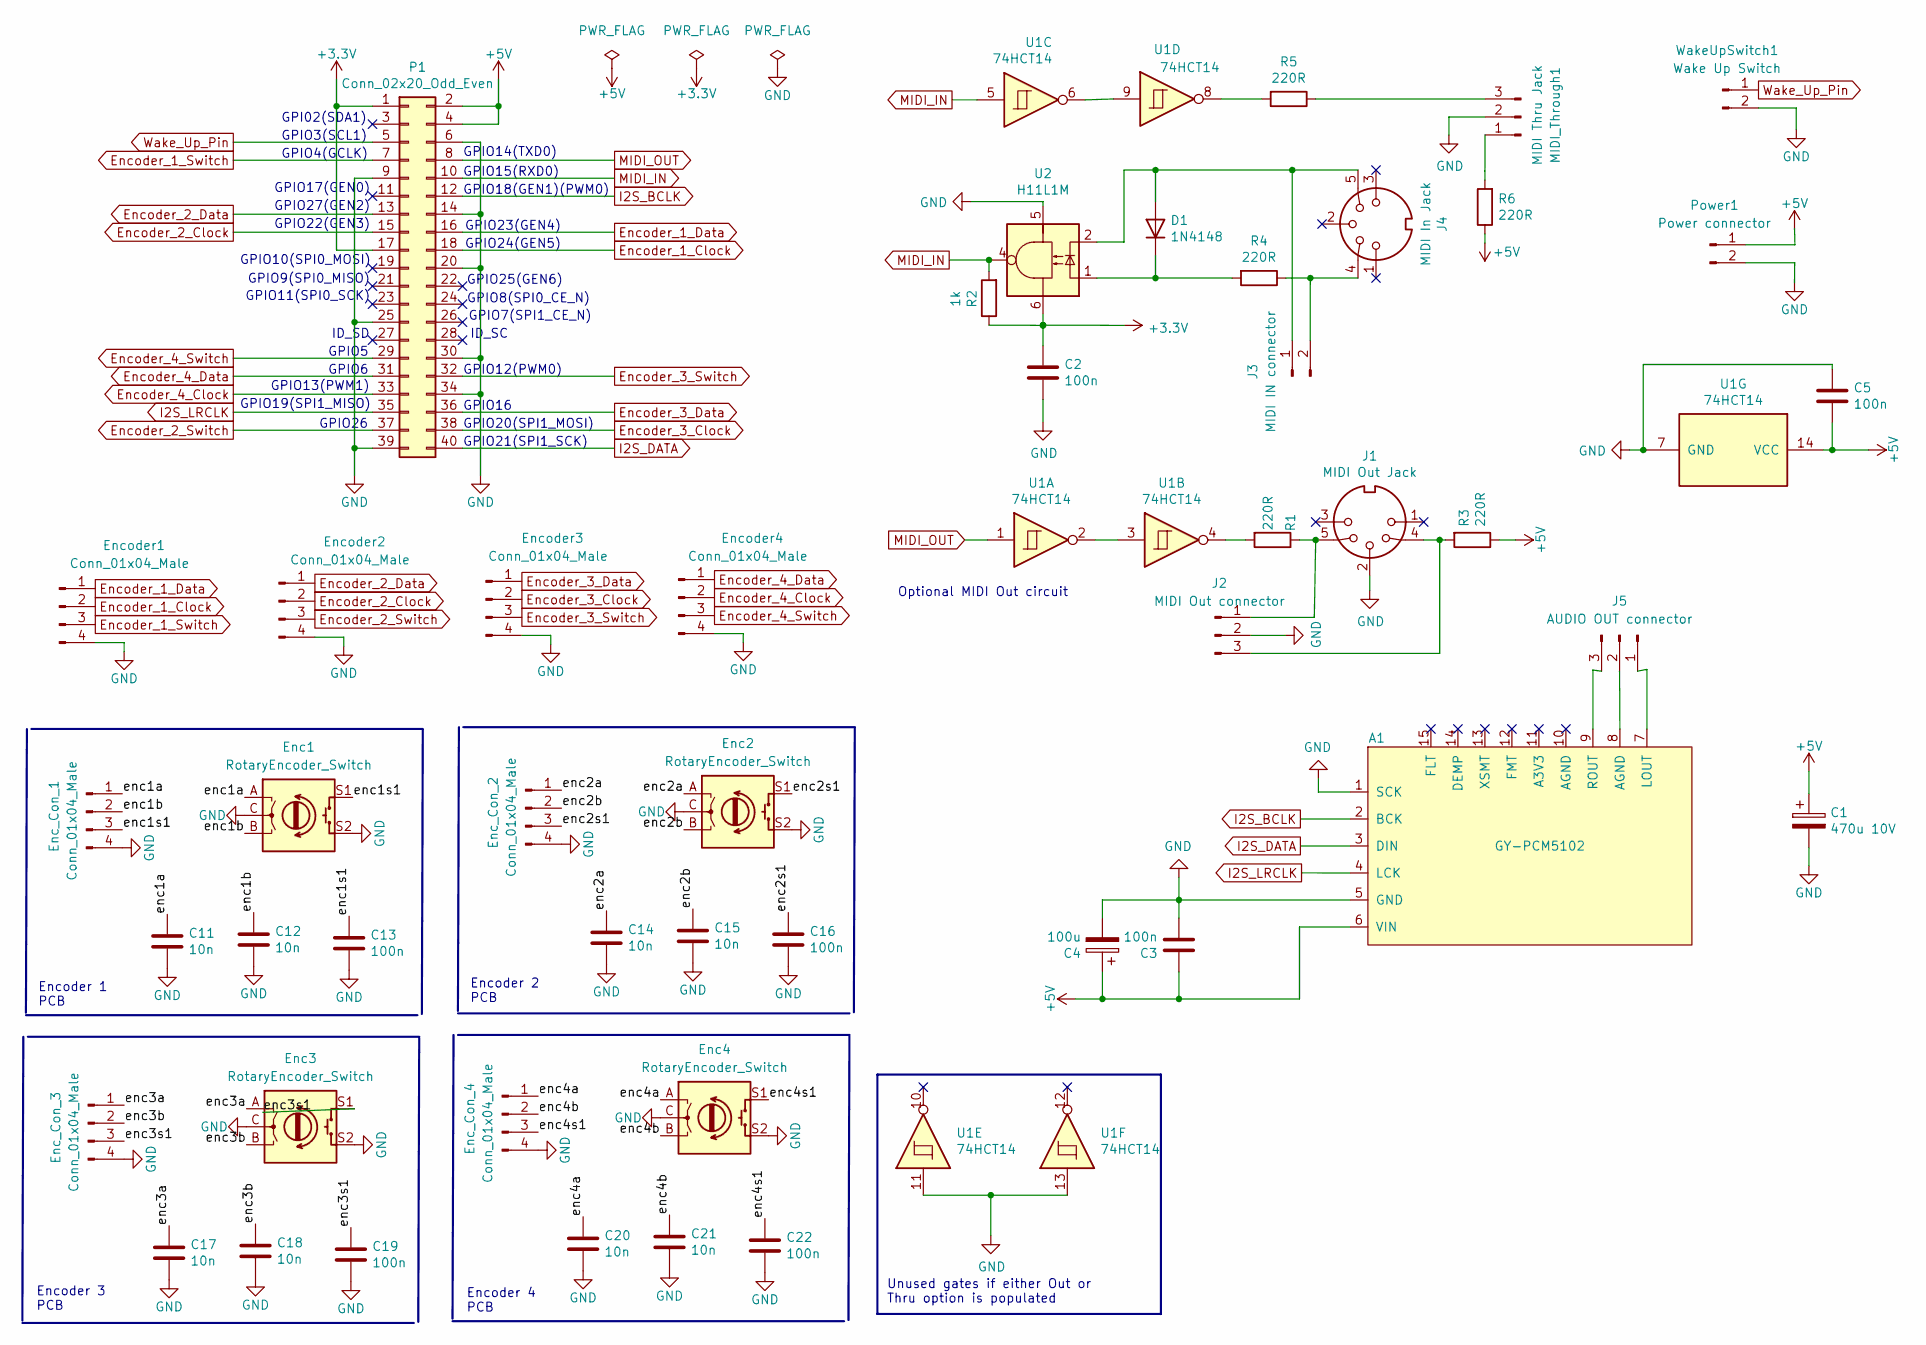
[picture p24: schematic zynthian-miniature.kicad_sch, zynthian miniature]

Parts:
A1: GY-PCM5102
C1: 470u 10V; CP_Radial_D8.0mm_P3.50mm
C2, C3, C5: 100n; C_Rect_L7.0mm_W2.0mm_P5.00mm
C4: 100u; CP_Radial_D6.3mm_P2.50mm
C11, C12, C14, C15, C17, C18, C20, C21: 10n; C_Rect_L4.0mm_W2.5mm_P2.50mm
C13, C16, C19, C22: 100n; C_Rect_L4.0mm_W2.5mm_P2.50mm
D1: 1N4148; D_DO-35_SOD27_P7.62mm_Horizontal
Enc1, Enc2, Enc3, Enc4: RotaryEncoder_Switch; RotaryEncoder_Alps_EC12E-Switch_Vertical_H20mm
Enc_Con_1, Enc_Con_2, Enc_Con_3, Enc_Con_4: Conn_01x04_Male; PinHeader_1x04_P2.54mm_Vertical
Encoder1, Encoder2, Encoder3, Encoder4: Conn_01x04_Male; PinHeader_1x04_P2.54mm_Vertical
J1: MIDI Out Jack; MultiDIN5
J2: MIDI Out connector; PinHeader_1x03_P2.54mm_Vertical
J3: MIDI IN connector; PinHeader_1x02_P2.54mm_Vertical
J4: MIDI In Jack; MultiDIN5
J5: AUDIO OUT connector; PinHeader_1x03_P2.54mm_Vertical
MIDI_Through1: MIDI Thru Jack; PinHeader_1x03_P2.54mm_Vertical
P1: Conn_02x20_Odd_Even; PinSocket_2x20_P2.54mm_Vertical
Power1: Power connector; PinHeader_1x02_P2.54mm_Vertical
R1, R3, R4, R5, R6: 220R; R_Axial_DIN0207_L6.3mm_D2.5mm_P7.62mm_Horizontal
R2: 1k; R_Axial_DIN0207_L6.3mm_D2.5mm_P7.62mm_Horizontal
U1: 74HCT14; DIP-14_W7.62mm
U2: H11L1M; DIP-6_W7.62mm
WakeUpSwitch1: Wake Up Switch; PinHeader_1x02_P2.54mm_Vertical

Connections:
+3.3V: C2.1, P1.1, P1.17, R2.1, U2.6
+5V: A1.6 (VIN), C1.1, C3.1, C4.1, C5.2, P1.2, P1.4, Power1.1, R3.1, R6.1, U1.14 (VCC)
/enc1a: C11.1, Enc1.A, Enc_Con_1.1
/enc1b: C12.1, Enc1.B, Enc_Con_1.2
/enc1s1: C13.1, Enc1.S1, Enc_Con_1.3
/enc2a: C14.1, Enc2.A, Enc_Con_2.1
/enc2b: C15.1, Enc2.B, Enc_Con_2.2
/enc2s1: C16.1, Enc2.S1, Enc_Con_2.3
/enc3a: C17.1, Enc3.A, Enc_Con_3.1
/enc3b: C18.1, Enc3.B, Enc_Con_3.2
/enc3s1: C19.1, Enc3.S1, Enc_Con_3.3
/enc4a: C20.1, Enc4.A, Enc_Con_4.1
/enc4b: C21.1, Enc4.B, Enc_Con_4.2
/enc4s1: C22.1, Enc4.S1, Enc_Con_4.3
Encoder_1_Clock: Encoder1.2, P1.18
Encoder_1_Data: Encoder1.1, P1.16
Encoder_1_Switch: Encoder1.3, P1.7
Encoder_2_Clock: Encoder2.2, P1.15
Encoder_2_Data: Encoder2.1, P1.13
Encoder_2_Switch: Encoder2.3, P1.37
Encoder_3_Clock: Encoder3.2, P1.38
Encoder_3_Data: Encoder3.1, P1.36
Encoder_3_Switch: Encoder3.3, P1.32
Encoder_4_Clock: Encoder4.2, P1.33
Encoder_4_Data: Encoder4.1, P1.31
Encoder_4_Switch: Encoder4.3, P1.29
GND: A1.1 (SCK), A1.5 (GND), C1.2, C2.2, C3.2, C4.2, C5.1, C11.2, C12.2, C13.2, C14.2, C15.2, C16.2, C17.2, C18.2, C19.2, C20.2, C21.2, C22.2, Enc1.C, Enc1.S2, Enc2.C, Enc2.S2, Enc3.C, Enc3.S2, Enc4.C, Enc4.S2, Enc_Con_1.4, Enc_Con_2.4, Enc_Con_3.4, Enc_Con_4.4, Encoder1.4, Encoder2.4, Encoder3.4, Encoder4.4, J1.2, J2.2, MIDI_Through1.2, P1.6, P1.9, P1.14, P1.20, P1.25, P1.30, P1.34, P1.39, Power1.2, U1.7 (GND), U1.11, U1.13, U2.5, WakeUpSwitch1.2
I2S_BCLK: A1.2 (BCK), P1.12
I2S_DATA: A1.3 (DIN), P1.40
I2S_LRCLK: A1.4 (LCK), P1.35
MIDI_IN: P1.10, R2.2, U1.5, U2.4
MIDI_OUT: P1.8, U1.1
unnamed: A1.7 (LOUT), J5.1
unnamed: A1.8 (AGND), J5.2
unnamed: A1.9 (ROUT), J5.3
unnamed: D1.1 (K), R4.2, U2.1
unnamed: D1.2 (A), J3.1, J4.5, U2.2
unnamed: J1.4, J2.3, R3.2
unnamed: J1.5, J2.1, R1.1
unnamed: J3.2, J4.4, R4.1
unnamed: MIDI_Through1.1, R6.2
unnamed: MIDI_Through1.3, R5.1
unnamed: R1.2, U1.4
unnamed: R5.2, U1.8
unnamed: U1.2, U1.3
unnamed: U1.6, U1.9
Wake_Up_Pin: P1.5, WakeUpSwitch1.1

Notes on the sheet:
Encoder 1 PCB
GPIO13(PWM1)
ID_SC
GPIO22(GEN3)
GPIO7(SPI1_CE_N)
Encoder 3 PCB
GPIO12(PWM0)
Encoder 2 PCB
GPIO25(GEN6)
ID_SD
GPIO23(GEN4)
GPIO6
GPIO15(RXD0)
GPIO26
Encoder 4 PCB
GPIO10(SPI0_MOSI)
GPIO9(SPI0_MISO)
GPIO27(GEN2)
GPIO14(TXD0)
GPIO24(GEN5)
GPIO11(SPI0_SCK)
Optional MIDI Out circuit
GPIO5
GPIO19(SPI1_MISO)
Unused gates if either Out or Thru option is populated
GPIO17(GEN0)
GPIO4(GCLK)
GPIO8(SPI0_CE_N)
GPIO20(SPI1_MOSI)
GPI02(SDA1)
GPIO18(GEN1)(PWM0)
GPIO21(SPI1_SCK)
GPIO3(SCL1)
GPIO16

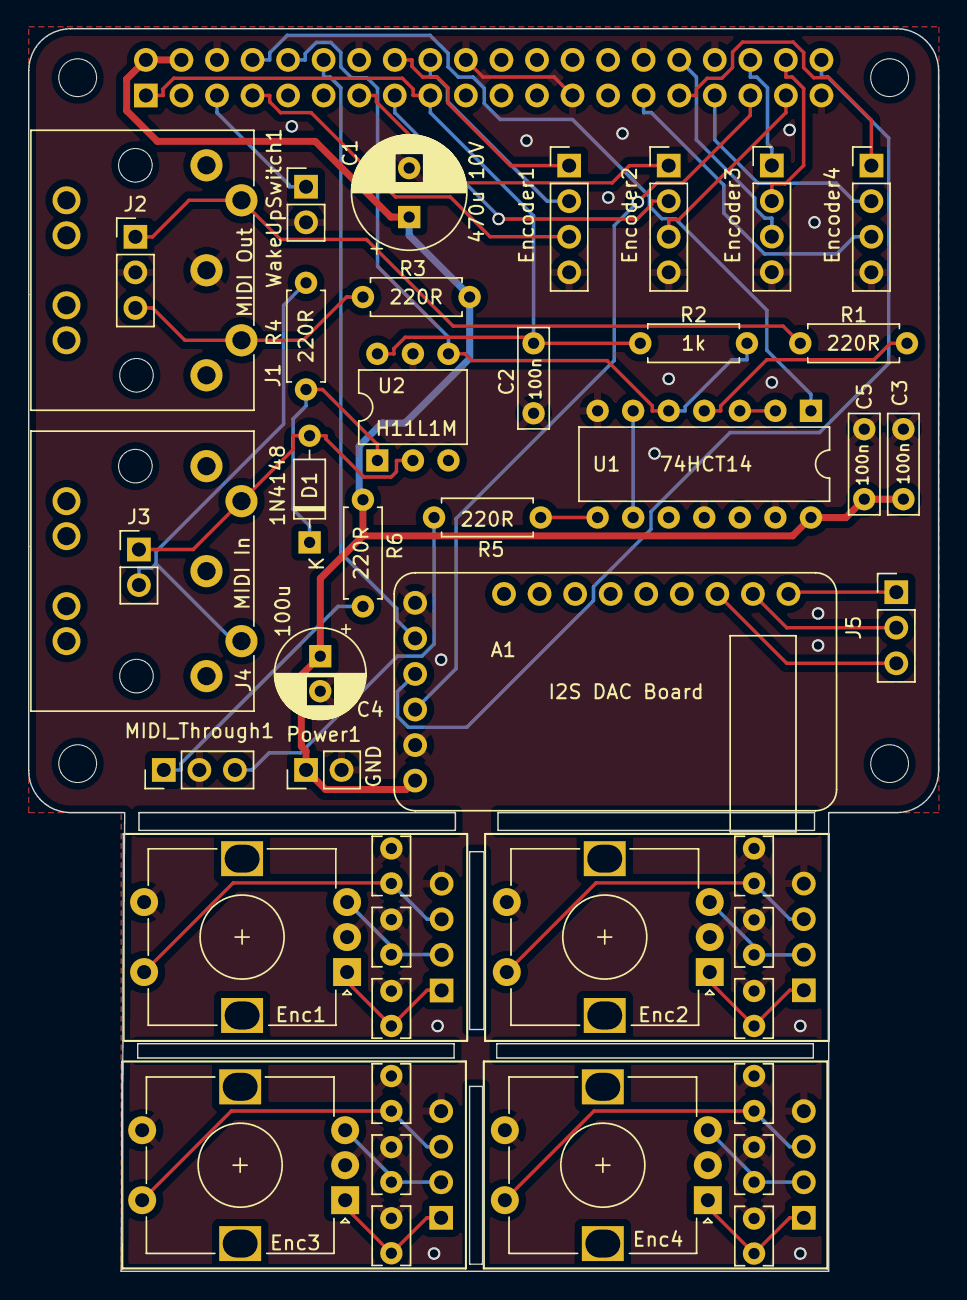
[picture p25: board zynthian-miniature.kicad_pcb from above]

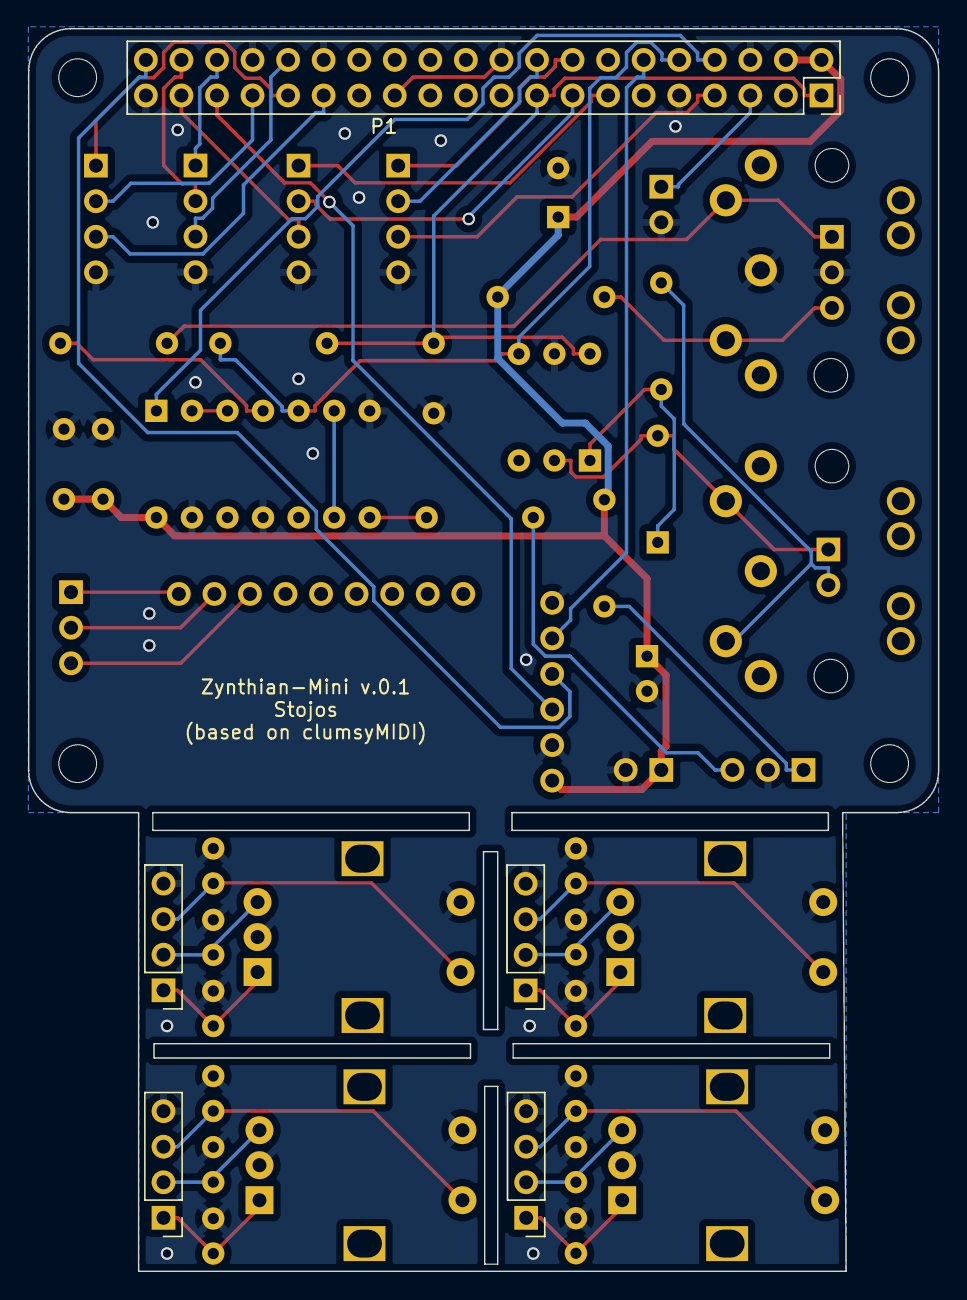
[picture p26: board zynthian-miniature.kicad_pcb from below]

Board: 2 copper layers, 65.0 x 88.8 mm, 52 parts (5 on the bottom side), 47 nets.

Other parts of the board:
MK1, MK2, MK3, MK4: M2.5; MountingHole_2.7mm_M2.5

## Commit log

2024-06-11 first release
    [0329.stl, 0329.stp, PCM5102-I2S.step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]
2024-06-11 added schematics
